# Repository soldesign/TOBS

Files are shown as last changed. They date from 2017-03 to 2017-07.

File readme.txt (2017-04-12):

Currently, 1.3 billion people live without access to electricity. Most of them are inhabitants of rural regions in developing south, that don’t have connection to the electricity grid. 
Fortunately, clean energy technologies have been reaching these people more and more in the past years. Mostly, but not only, in Bangladesh, a renewable energy revolution is taking place: the emergence of small scale solar-home-systems that supply electricity for lighting, cellphones and household appliances - in Bangladesh alone, there are already over 5 million solar-home-systems installed! These system feature a small PV panel with a charging controller and a battery (The solar home systems are usually financed with a micro loan from a microfinance institution, because its owner sometimes earn as little as one dollar per day).

To cut costs in these systems, lead-acid batteries are usually installed. Unfortunately, lead-acid batteries have a limited number of charge-discharge-cycles, much less than, for example, modern LIFEPO batteries. Also, they age quickly if they are discharged below around 40% of their capacity. This leads to many of the batteries breaking within 2 years or less, rendering the solar home systems unusable.

Moreover, as developing countries don’t have proficient infrastructure to dispose or recycle the lead-acid batteries, each failing battery leads to waste of resources and significant environmental pollution.

>lead acid batties are vulnurable to cycling often

How to solve the problem?

-retrofitting hybrid charge controller!

Using LIFEPO based batteries would significantly increase the solar home system’s lifetime­, as LIFEPO batteries are less affected by cycling compared to lead-acid batteries. However, initial high investment costs for LIFEPO batteries are often not feasible for developing markets. To get the best of both, a hybrid charge controller which supports a small lithium-ion battery and a bigger lead-acid battery simultaneously, would be ideal.

> LIFEPO batteries are better but too expensive 

A normal charge controller is responsible for monitoring the battery’s voltage and for controlling the charge and discharge cycle. In comparison, a hybrid charge controller would be able to switch between the two battery types, considering environmental factors, such as load current, solar irradiance and state of charge of both batteries. This will result in the li-ion battery having a smaller capacity, therefore cutting its cost. An algorithm would then only use the lead acid battery if the load is too big for the lithium ion battery to handle. For smaller loads and thus more cycles, the lithium ion battery would be used.

> lead acid battery will be cycled less often

Thus, the new hybrid charge controller aims to prolong the lifespan of millions of already existing lead acid batteries inside solar home systems by reducing sulfuration.

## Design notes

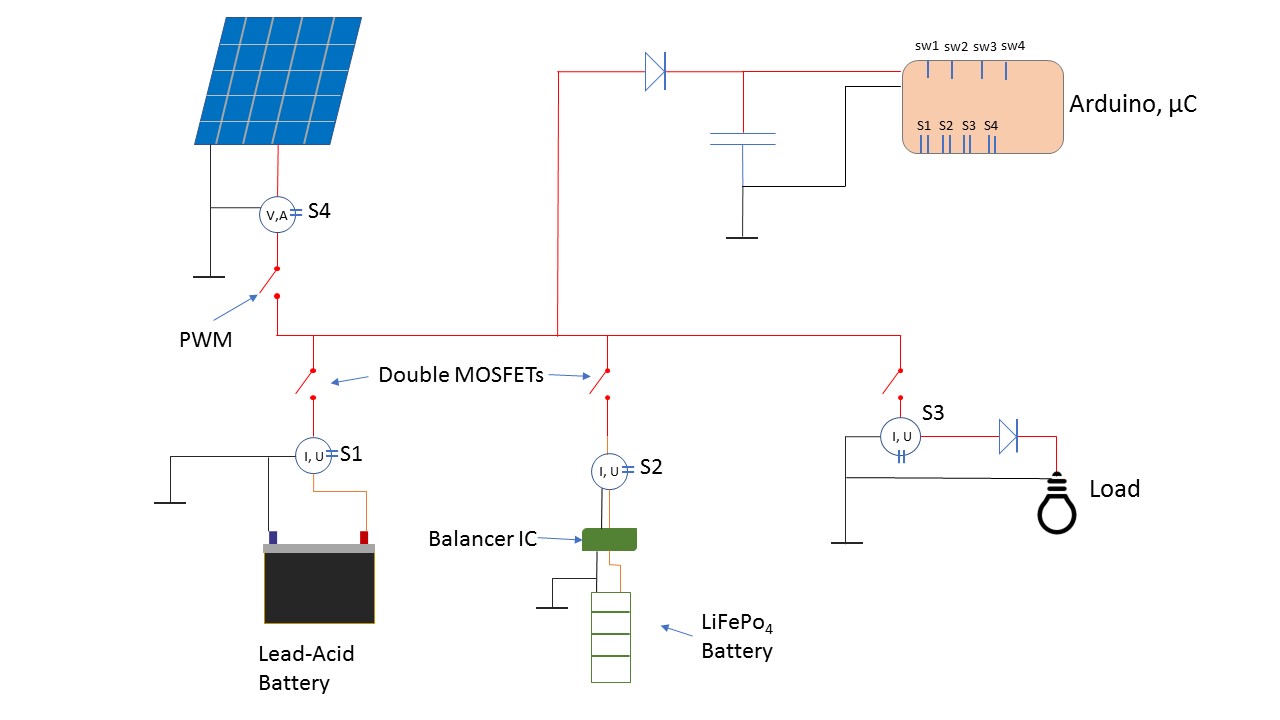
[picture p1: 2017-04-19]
TOBS-new pseudo schematic.jpg

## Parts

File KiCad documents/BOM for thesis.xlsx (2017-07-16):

Quantity | Value | Type | Price (10) | Price (100) | Reihenfolge | summ10 | summe100
1 | BQ76920 | Balancer | 2.87 | 2.77 | 1 | 2.87 | 2.77
1 | CD4051 | Multiplexer | 0.3 | 0.183 | 2 | 0.3 | 0.183
6 | IPD90P04P4L-04 | Power MOSFET | 1.15 | 0.875 | 3 | 6.9 | 5.25
2 | STL60P4LLF6 | MOSFET | 0.692 | 0.532 | 4 | 1.384 | 1.064
2 | BSS138 | Logic MOSFET | 0.159 | 0.066 | 5 | 0.318 | 0.132
6 | MMBT3904 | Logic transistor | 0.16 | 0.14 | 6 | 0.96 | 0.84
1 | VSB2045Y-M3/54 | Schottky | 0.967 | 0.829 | 7 | 0.967 | 0.829
1 | 1N4148-T | Diode | 0.022 | 0.018 | 8 | 0.022 | 0.018
3 | LM358D | Op-Amp | 0.266 | 0.144 | 9 | 0.798 | 0.432
2 | 15A | Fuse |  |  | 10 | 0 | 0
4 | R005 | Shunt |  |  | 11 | 0 | 0
6 | 220k | Resistor |  |  | 12 | 0 | 0
7 | 100k | Resistor |  |  | 13 | 0 | 0
5 | 47k | Resistor |  |  | 14 | 0 | 0
2 | 33k | Resistor |  |  | 15 | 0 | 0
17 | 10k | Resistor |  |  | 16 | 0 | 0
6 | 4.7k | Resistor |  |  | 17 | 0 | 0
1 | 2.2k | Resistor |  |  | 18 | 0 | 0
8 | 100 | Resistor |  |  | 19 | 0 | 0
2 | 10µ | Capacitor |  |  | 20 | 0 | 0
6 | 1µ | Capacitor |  |  | 21 | 0 | 0
3 | 0.1µ | Capacitor |  |  | 22 | 0 | 0
4 | 5mm pitch | Screw Terminal | 0.24 | 0.2 | 23 | 0.96 | 0.8
1 | 1x6 female | Pin header | 0.26 | 0.23 | 24 | 0.26 | 0.23
2 | 1x8 male | Pin header | 0.22 | 0.2 | 25 | 0.44 | 0.4
2 | 1x6 male | Pin header | 0.16 | 0.13 | 26 | 0.32 | 0.26
1 | 1x3 male | Pin header | 0.08 | 0.06 | 27 | 0.08 | 0.06
 |  | Sum | 16.579 | 13.268 |  | 16.579 | 13.268

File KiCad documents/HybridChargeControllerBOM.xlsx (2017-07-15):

Reference | Quantity | Value | Footprint | Readable Name | Type | SMD? | Price 10 | Price 100
AU1 | 1 | Uno Layout | Arduinos:ARDUINO_SHIELD_bigger_holes_no_outline | 2x8, 2x6 male | Pin header | n
C1 C2 C3 C4 C6 C7 | 6 | 1µ | Capacitors_SMD:C_0603_HandSoldering | 1µ | Capacitor | y
C11 C9 | 2 | 10µ | Capacitors_ThroughHole:CP_Radial_D5.0mm_P2.00mm | 10µ | Capacitor | n
C10 C5 C8 | 3 | 0.1µ | Capacitors_SMD:C_0603_HandSoldering | 0.1µ | Capacitor | y
D2 | 1 | 1N4148-T | Diodes_ThroughHole:D_DO-35_SOD27_P10.16mm_Horizontal | 1N4148-T | Diode | y
D3 | 1 | VSB2045Y-M3/54 | Diodes_ThroughHole:D_P600_R-6_P12.70mm_Horizontal | VSB2045Y-M3/54 | Diode | n
F1 F2 | 2 | 15A | Fuse_Holders_and_Fuses:Fuse_SMD1206_HandSoldering | 15A | Fuse | y
P1 P3 P5 P6 | 4 | Load | VCS_library:TerminalBlock_Screw_2pol | Terminal | Screw Terminal | n
P2 | 1 | LI_balancer | Pin_Headers:Pin_Header_Straight_1x03_Pitch2.54mm | 3 pin header male | Pin header | n
P4 | 1 | Extra | Pin_Headers:Pin_Header_Straight_1x05_Pitch2.54mm | 5 pin header female | Pin header | n
P7 | 1 | FTDI | Pin_Headers:Pin_Header_Straight_1x06_Pitch2.54mm | 6 pin header female | Pin header | n
Q1 Q10 Q3 Q6 Q7 Q8 | 6 | MMBT3904 | TO_SOT_Packages_SMD:SOT-23 | MMBT3904 |  | y
Q12 Q13 | 2 | STL60P4LLF6 | bachelorSMDs:powerFLAT_5x6_5..8com | STL60P4LLF6 |  | y
Q15 Q16 | 2 | BSS138 | TO_SOT_Packages_SMD:SOT-23 | BSS138 |  | y
Q11 Q14 Q2 Q4 Q5 Q9 | 6 | IPD90P04P4L-04 | TO_SOT_Packages_SMD:TO-252-3_TabPin2 | IPD90P04P4L-04 |  | y
R15 R21 R29 R34 R43 R47 | 6 | 4.7k | Resistors_SMD:R_0603_HandSoldering | 4.7k |  | y
R16 R17 R32 R44 | 4 | R005 | Resistors_SMD:R_1206_HandSoldering | shunt |  | y
R10 R14 R18 R2 R3 R4 R5 R6 | 8 | 100 | Resistors_SMD:R_0603_HandSoldering | 100 |  | y
R19 R20 R31 R36 R45 R46 | 6 | 220k | Resistors_SMD:R_0603_HandSoldering | 220k |  | y
R1 R11 R13 R22 R23 R24 R25 R26 R27 R33 R38 R48 R49 R53 R54 R55 R56 | 17 | 10k | Resistors_SMD:R_0603_HandSoldering | 10k |  | y
R28 R35 R39 R41 R51 R7 R9 | 7 | 100k | Resistors_SMD:R_0603_HandSoldering | 100k |  | y
R12 R30 R37 R50 R52 | 5 | 47k | Resistors_SMD:R_0603_HandSoldering | 47k |  | y
R40 | 1 | 2.2k | Resistors_SMD:R_0603_HandSoldering | 2.2k |  | y
R42 R8 | 2 | 33k | Resistors_SMD:R_0603_HandSoldering | 33k |  | y
U1 U4 U5 | 3 | LM358D | SMD_Packages:SOIC-8-N | LM358D |  | y
U2 | 1 | bq76920 | SMD_Packages:SSOP-20 | bq76920 |  | y
U3 | 1 | cd4051 | SMD_Packages:SO-16-N | cd4051 |  | y

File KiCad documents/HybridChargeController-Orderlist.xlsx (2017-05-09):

Reference | Quantity | Value | Auf Lager
C10 C5 C8 | 3 | 0.1µ | x
C1 C2 C3 C4 C6 C7 | 6 | 1µ | x
C11 C9 | 2 | 10µ | x
R1 R10 R14 R17 R2 R3 R4 R5 | 8 | 100 | x
R35 R39 R41 R7 R9 | 5 | 100k | x
R11 R13 R22 R23 R26 R28 R29 R38 R48 R49 R6 | 11 | 10k | x
F1 F2 | 2 | 15A | x
R24 R25 R27 | 3 | 1M | n
D1 D2 | 2 | 1N4148-T | n
R40 | 1 | 2.2k | n
R19 R20 R32 R36 R45 R46 | 6 | 220k | x
Q1 Q10 Q7 Q8 | 4 | MMBT3904 | n
R42 R8 | 2 | 33k | x
R15 R21 R30 R34 R43 R47 | 6 | 4.7k | n
R12 R31 R37 | 3 | 47k | n
U2 | 1 | bq76920 | n
Q4 | 1 | BSS138 | n
U3 | 1 | cd4051 | n
P4 | 1 | Extra | x
Q11 Q2 Q6 Q9 | 4 | IPD90P04P4_05 | n
P6 | 1 | LA | x
P5 | 1 | LI | x
P2 | 1 | LI_balancer | x
U1 U4 | 2 | LM358 | x
P1 | 1 | Load | x
P3 | 1 | PV | x
R16 R18 R33 R44 | 4 | R005 | x
Q3 Q5 | 2 | RQ3E100BNTB | n
Q12 Q13 | 2 | STL60P4LLF6 | n
AU1 | 1 | Uno Layout | x
D3 | 1 | VSB2045Y-M3/54 | n

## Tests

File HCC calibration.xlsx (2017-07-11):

 | Battery |  | PV |  | LOAD
 | Voltage |  | Voltage |  | Voltage
 | Input | Output | Input | Output | Input | Output
INPUT | 13360 | 679 | 10560 | 516.92 | 1 | 1
 | 11800 | 600 | 12140 | 596.83 | 0 | 0
 | 10320 | 525.6 | 14750 | 728.75
 | 14470 | 735.98
 | Current |  | Current |  | Current
 | Input | Output | Input | Output | Input | Output
INPUT | 31 | 487.85 | 0 | 492.9 | 0 | 495.35
 | 289 | 504.6 | 31.9 | 495.18 | 290 | 477.9
 | -5 | 485.83 | 326.4 | 513.5 | 2960 | 316.6
 | 3010 | 679.4 |  |  | 1990 | 375.7
 |  |  |  |  | 1120 | 428.4
PARAMETERS | Battery Voltage |  | PV Voltage |  | LOAD Voltage
 | 19.7333 | -45.9976 | 19.7805 | 334.8203 | 1.0000 | 0.0000
 | 1.0000 |  | 1.0000 |  | 1.0000
 | Battery Current |  | PV Current |  | LOAD Current
 | 15.5647 | -7564.6633 | 15.9332 | -7855.5799 | -16.5688 | 8210.8356
 | 0.9999984 |  | 0.9998 |  | 1.0000
OUTPUT | batterysensor.setcalibration(19.7333, -45.9976, 15.5647, -7564.6633); pvsensor.setcalibration(19.7805, 334.8203, 15.9332, -7855.5799); ldsensor.setcalibration(1, 0, -16.5688, 8210.8356);

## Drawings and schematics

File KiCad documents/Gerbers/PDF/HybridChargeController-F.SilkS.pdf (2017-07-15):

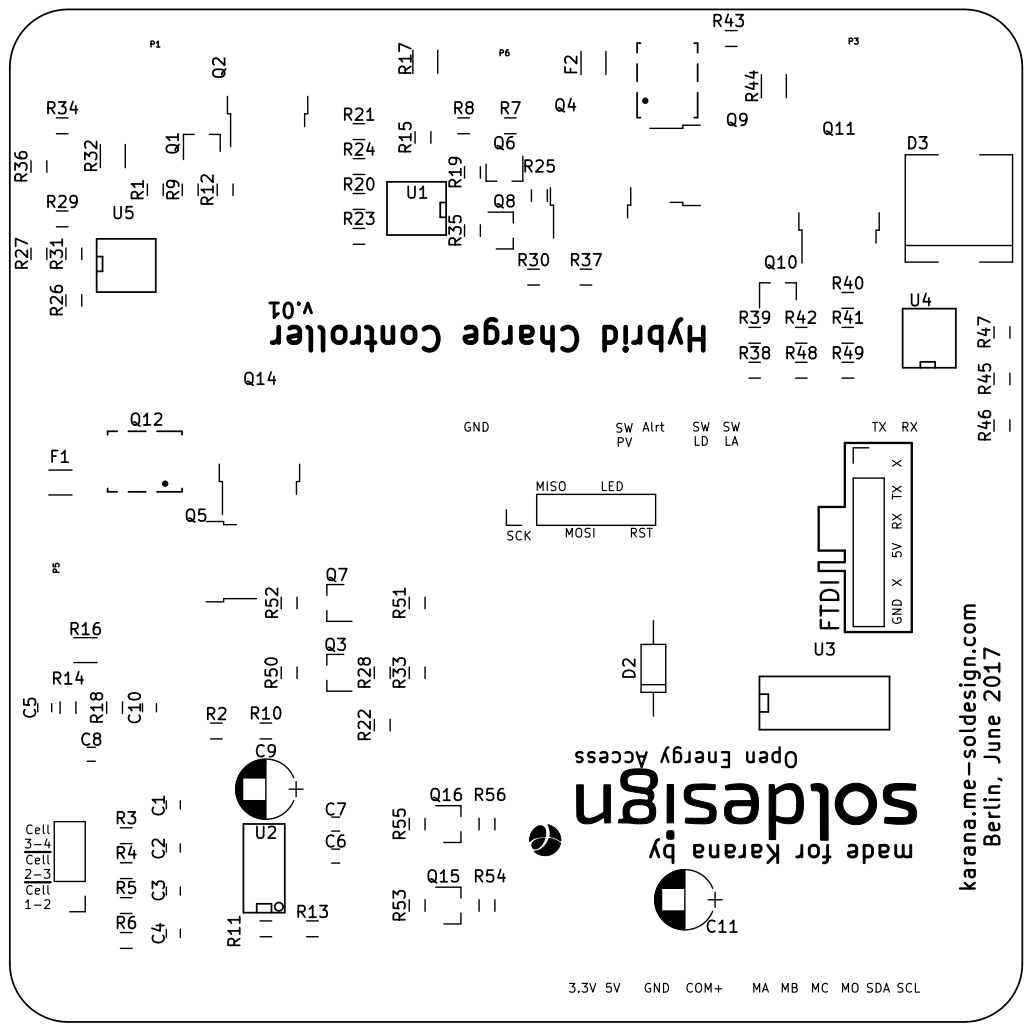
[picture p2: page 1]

FTDI X GND X 5V RX TX karana.me-soldesign.com Berlin, June 2017

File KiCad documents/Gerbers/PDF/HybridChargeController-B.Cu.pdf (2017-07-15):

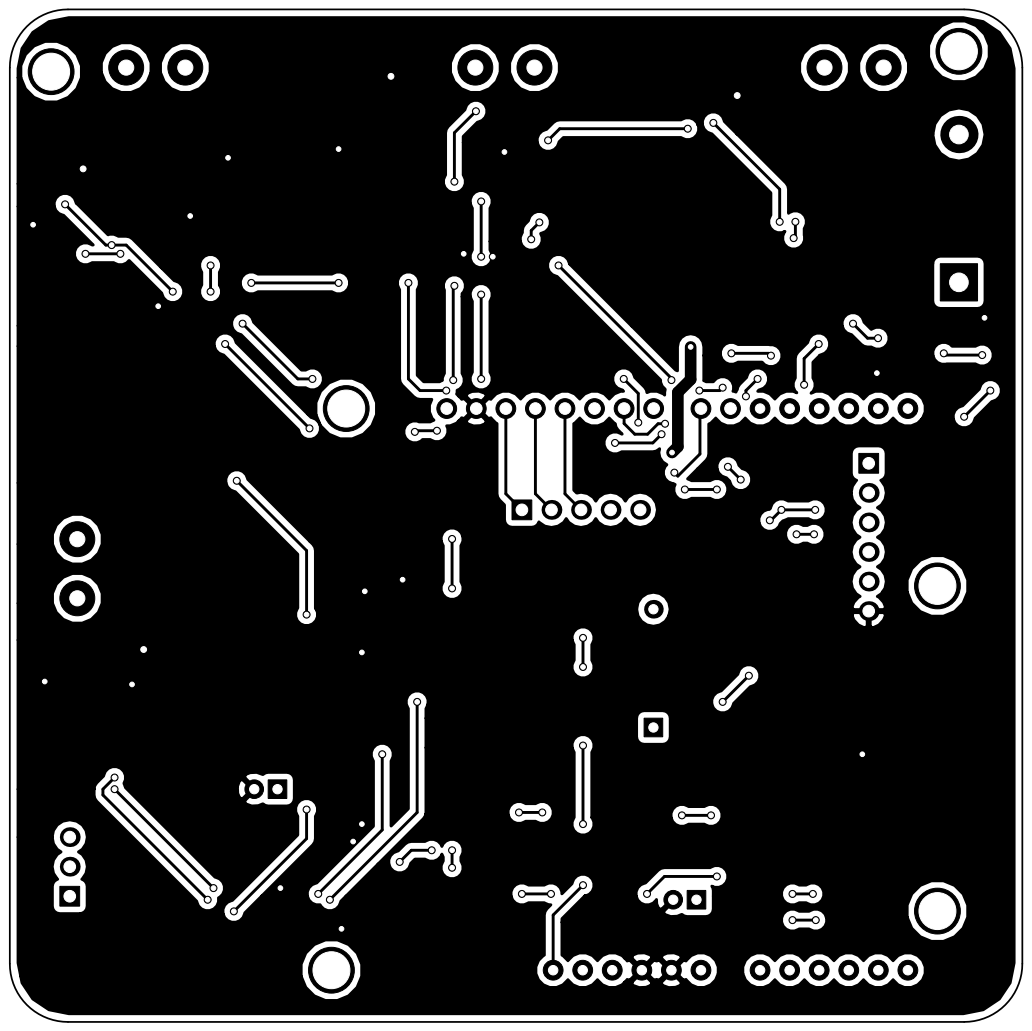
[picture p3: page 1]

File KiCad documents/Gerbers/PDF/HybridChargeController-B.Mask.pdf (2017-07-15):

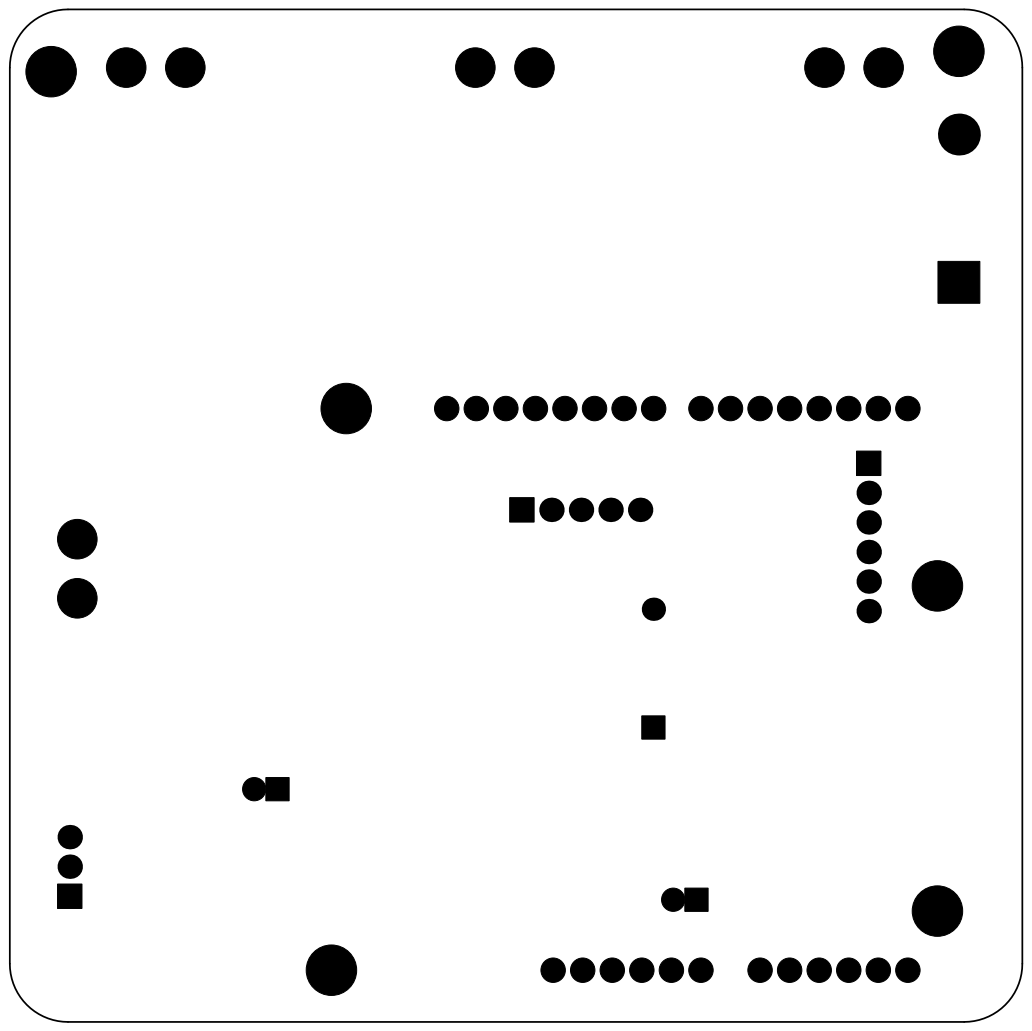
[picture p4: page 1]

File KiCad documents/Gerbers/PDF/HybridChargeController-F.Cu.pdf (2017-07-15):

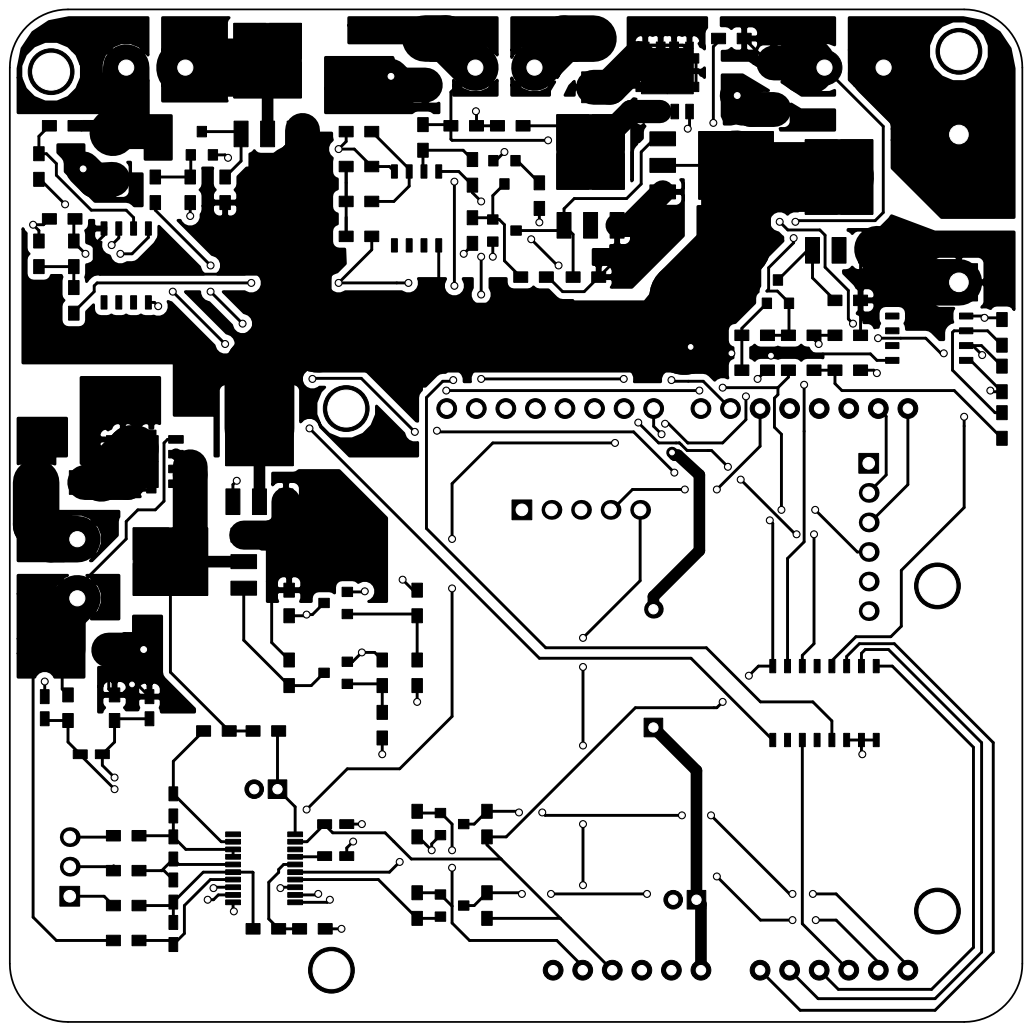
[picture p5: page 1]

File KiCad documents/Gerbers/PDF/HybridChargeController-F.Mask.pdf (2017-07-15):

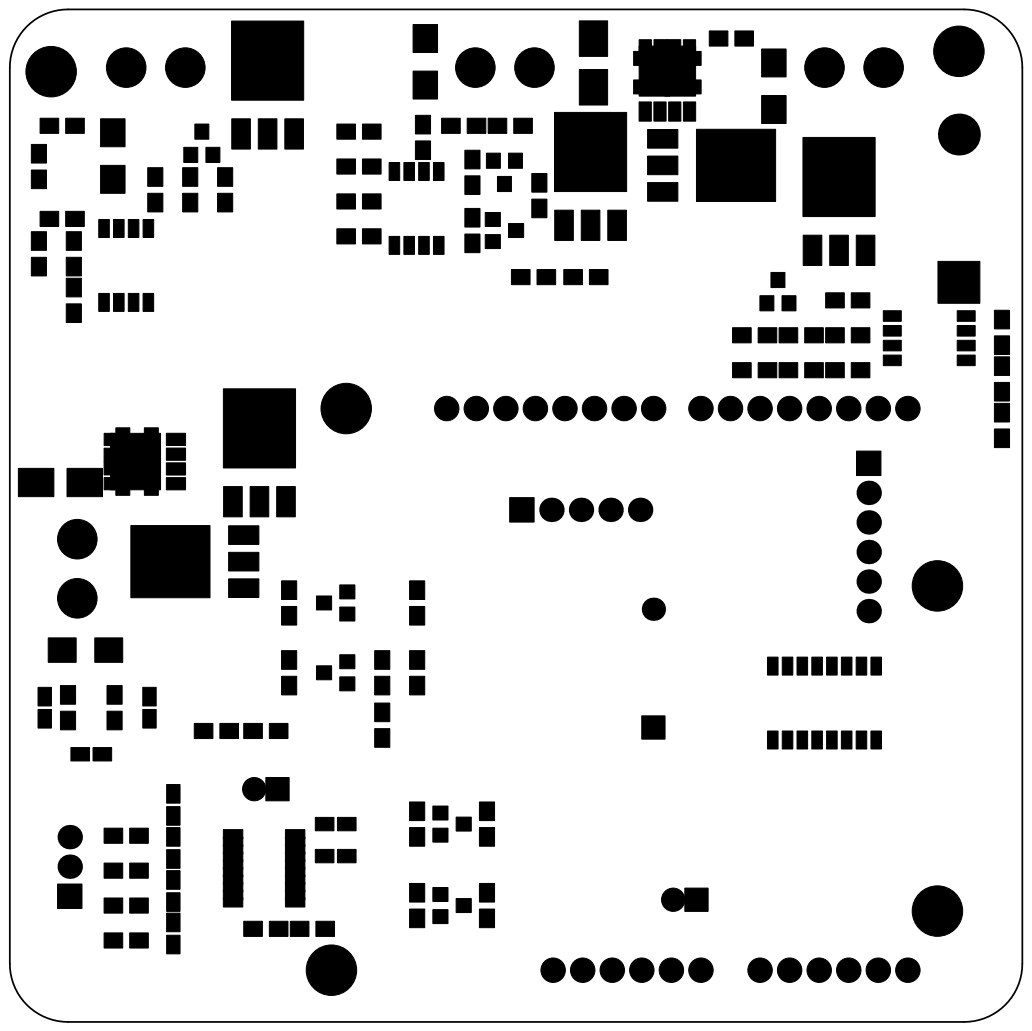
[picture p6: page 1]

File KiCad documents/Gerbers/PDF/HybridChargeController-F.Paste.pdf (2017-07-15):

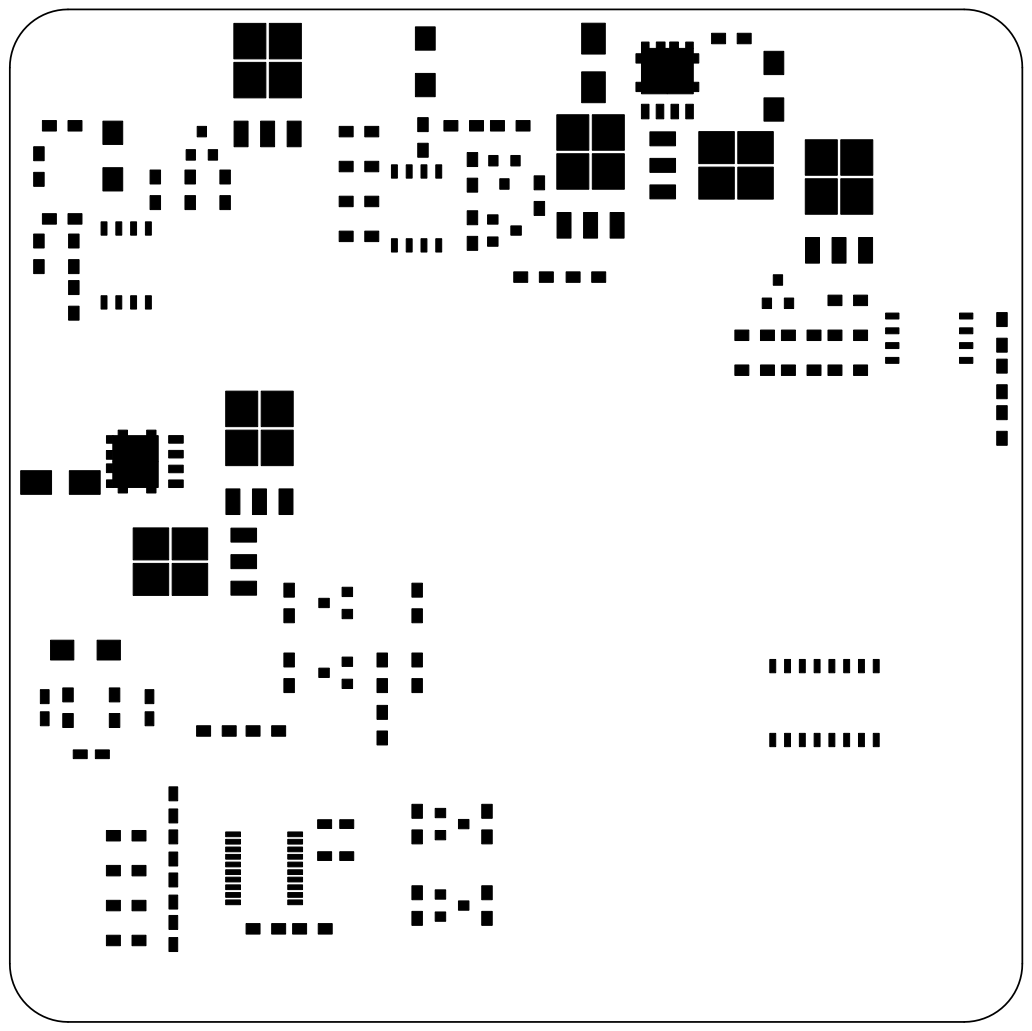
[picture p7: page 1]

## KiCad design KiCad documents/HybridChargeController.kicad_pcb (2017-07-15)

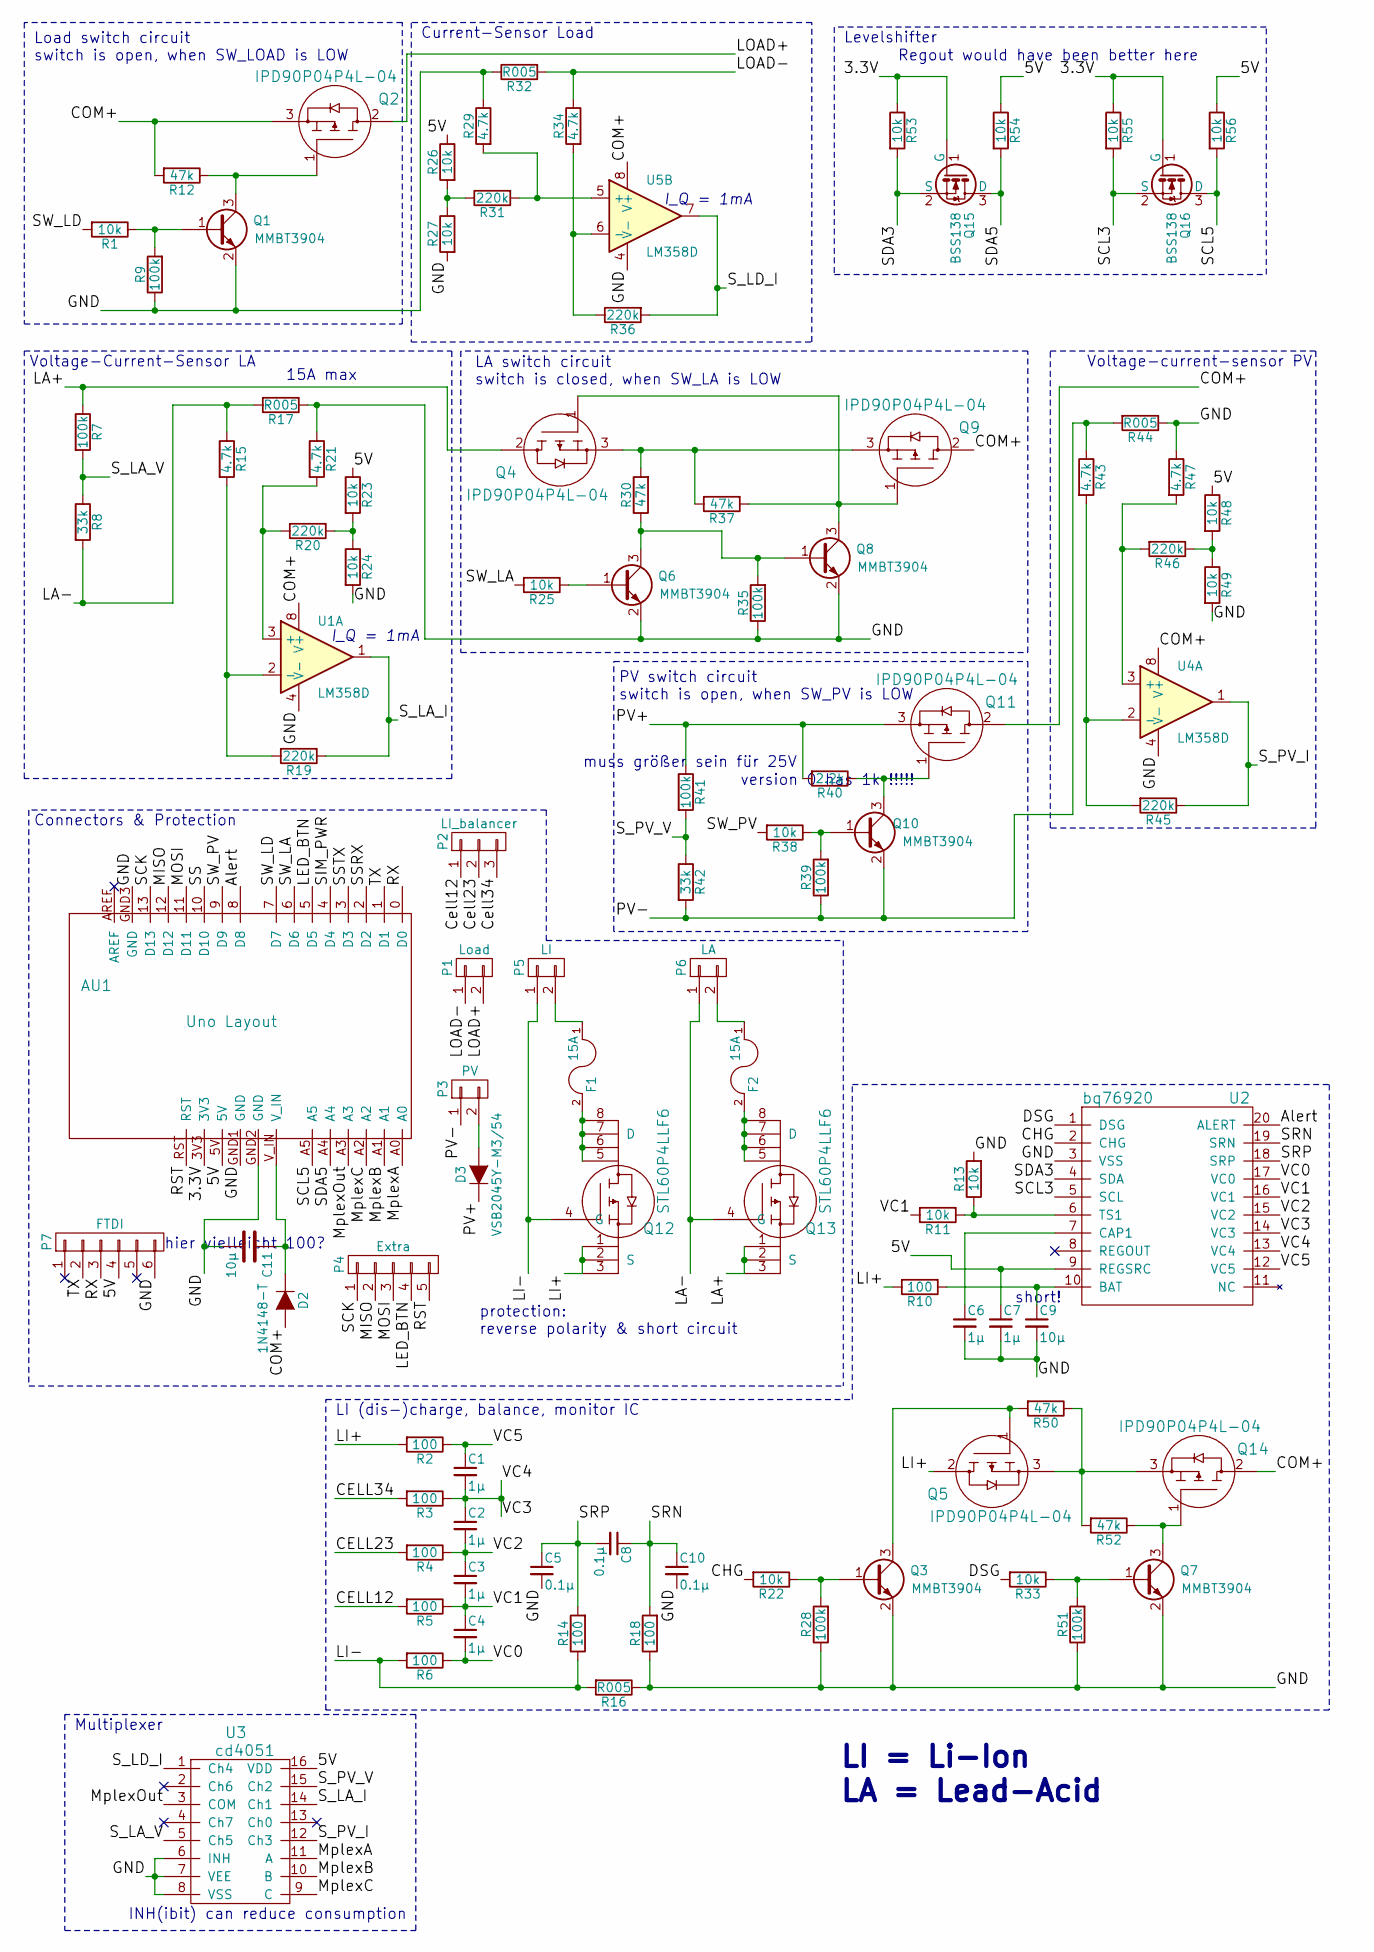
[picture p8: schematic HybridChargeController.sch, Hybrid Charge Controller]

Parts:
AU1: Uno Layout; ARDUINO_SHIELD_bigger_holes_no_outline
C1, C2, C3, C4, C6, C7: 1µ; C_0603_HandSoldering
C5, C8, C10: 0.1µ; C_0603_HandSoldering
C9, C11: 10µ; CP_Radial_D5.0mm_P2.00mm
D2: 1N4148-T; D_DO-35_SOD27_P10.16mm_Horizontal
D3: VSB2045Y-M3/54; D_P600_R-6_P12.70mm_Horizontal
F1, F2: 15A; Fuse_SMD1206_HandSoldering
P1: Load; TerminalBlock_Screw_2pol
P2: LI_balancer; Pin_Header_Straight_1x03_Pitch2.54mm
P3: PV; TerminalBlock_Screw_2pol
P4: Extra; Pin_Header_Straight_1x05_Pitch2.54mm
P5: LI; TerminalBlock_Screw_2pol
P6: LA; TerminalBlock_Screw_2pol
P7: FTDI; Pin_Header_Straight_1x06_Pitch2.54mm
Q1, Q3, Q6, Q7, Q8, Q10: MMBT3904; SOT-23
Q2, Q4, Q5, Q9, Q11, Q14: IPD90P04P4L-04; TO-252-3_TabPin2
Q12, Q13: STL60P4LLF6; powerFLAT_5x6_5..8com
Q15, Q16: BSS138; SOT-23
R1, R11, R13, R22, R23, R24, R25, R26, R27, R33, R38, R48, R49, R53, R54, R55, R56: 10k; R_0603_HandSoldering
R2, R3, R4, R5, R6, R10, R14, R18: 100; R_0603_HandSoldering
R7, R9, R28, R35, R39, R41, R51: 100k; R_0603_HandSoldering
R8, R42: 33k; R_0603_HandSoldering
R12, R30, R37, R50, R52: 47k; R_0603_HandSoldering
R15, R21, R29, R34, R43, R47: 4.7k; R_0603_HandSoldering
R16, R17, R32, R44: R005; R_1206_HandSoldering
R19, R20, R31, R36, R45, R46: 220k; R_0603_HandSoldering
R40: 2.2k; R_0603_HandSoldering
U1, U4, U5: LM358D; SOIC-8-N
U2: bq76920; SSOP-20
U3: cd4051; SO-16-N

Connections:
/3.3V: AU1.3V3, Q15.1 (G), Q16.1 (G), R53.1, R55.1
/5V: AU1.5V, C7.1, P7.4, R23.1, R26.1, R48.1, R54.1, R56.1, U2.9 (REGSRC), U3.16 (VDD)
/Alert: AU1.8 (D8), U2.20 (ALERT)
/CELL12: P2.1, R5.2
/CELL23: P2.2, R4.2
/CELL34: P2.3, R3.2
/CHG: R22.2, U2.2 (CHG)
/COM+: D2.2 (A), Q2.3, Q9.2, Q11.2, Q14.2, R12.2, U1.8 (V+), U4.8 (V+), U5.8 (V+)
/DSG: R33.2, U2.1 (DSG)
/GND: AU1.GND1 (GND), AU1.GND2 (GND), AU1.GND3 (GND), C5.2, C6.2, C7.2, C9.2, C10.2, C11.2, P7.6, Q1.2 (E), Q3.2 (E), Q6.2 (E), Q7.2 (E), Q8.2 (E), R9.1, R13.2, R16.1, R17.1, R18.1, R21.1, R24.2, R27.2, R28.1, R29.1, R32.1, R35.1, R44.1, R47.1, R49.2, R51.1, U1.4 (V-), U2.3 (VSS), U3.6 (INH), U3.7 (VEE), U3.8 (VSS), U4.4 (V-), U5.4 (V-)
/LA+: Q4.2, Q13.1, Q13.2 (S), Q13.3, R7.1
/LA-: P6.1, Q13.4 (G), R8.2, R15.1, R17.2
/LED_BTN: AU1.5 (D5), P4.4
/LI+: Q5.2, Q12.1, Q12.2 (S), Q12.3, R2.2, R10.2
/LI-: P5.1, Q12.4 (G), R6.2, R14.1, R16.2
/LOAD+: P1.2, Q2.2
/LOAD-: P1.1, R32.2, R34.1
/MISO: AU1.12 (D12), P4.2
/MOSI: AU1.11 (D11), P4.3
/MplexA: AU1.A0, U3.11 (A)
/MplexB: AU1.A1, U3.10 (B)
/MplexC: AU1.A2, U3.9 (C)
/MplexOut: AU1.A3, U3.3 (COM)
/PV+: D3.1 (K), Q11.3, R40.2, R41.1
/PV-: P3.1, Q10.2 (E), R39.1, R42.2, R43.1, R44.2
/RST: AU1.RST, P4.5
/RX: AU1.0 (D0), P7.3
/SCK: AU1.13 (D13), P4.1
/SCL3: Q16.2 (S), R55.2, U2.5 (SCL)
/SCL5: AU1.A5, Q16.3 (D), R56.2
/SDA3: Q15.2 (S), R53.2, U2.4 (SDA)
/SDA5: AU1.A4, Q15.3 (D), R54.2
/SIM_PWR: AU1.4 (D4)
/SRN: C8.1, C10.1, R18.2, U2.19 (SRN)
/SRP: C5.1, C8.2, R14.2, U2.18 (SRP)
/SS: AU1.10 (D10)
/SSRX: AU1.2 (D2)
/SSTX: AU1.3 (D3)
/SW_LA: AU1.6 (D6), R25.2
/SW_LD: AU1.7 (D7), R1.2
/SW_PV: AU1.9 (D9), R38.2
/S_LA_I: R19.1, U1.1, U3.14 (Ch1)
/S_LA_V: R7.2, R8.1, U3.5 (Ch5)
/S_LD_I: R36.2, U3.1 (Ch4), U5.7
/S_PV_I: R45.1, U3.12 (Ch3), U4.1
/S_PV_V: R41.2, R42.1, U3.15 (Ch2)
/TX: AU1.1 (D1), P7.2
/VC0: C4.2, R6.1, U2.17 (VC0)
/VC1: C3.2, C4.1, R5.1, R11.2, U2.16 (VC1)
/VC2: C2.2, C3.1, R4.1, U2.15 (VC2)
/VC3: C1.2, C2.1, R3.1, U2.13 (VC4), U2.14 (VC3)
/VC5: C1.1, R2.1, U2.12 (VC5)
unnamed: AU1.V_IN, C11.1, D2.1 (K)
unnamed: C6.1, U2.7 (CAP1)
unnamed: C9.1, R10.1, U2.10 (BAT)
unnamed: D3.2 (A), P3.2
unnamed: F1.1, P5.2
unnamed: F1.2, Q12.5, Q12.6, Q12.7 (D), Q12.8
unnamed: F2.1, P6.2
unnamed: F2.2, Q13.5, Q13.6, Q13.7 (D), Q13.8
unnamed: Q1.1 (B), R1.1, R9.2
unnamed: Q1.3 (C), Q2.1, R12.1
unnamed: Q3.1 (B), R22.1, R28.2
unnamed: Q3.3 (C), Q5.1, R50.2
unnamed: Q4.1, Q8.3 (C), Q9.1, R37.1
unnamed: Q4.3, Q9.3, R30.2, R37.2
unnamed: Q6.1 (B), R25.1
unnamed: Q6.3 (C), Q8.1 (B), R30.1, R35.2
unnamed: Q7.1 (B), R33.1, R51.2
unnamed: Q10.1 (B), R38.1, R39.2
unnamed: Q10.3 (C), Q11.1, R40.1
unnamed: Q7.3 (C), Q14.1, R52.1
unnamed: Q5.3, Q14.3, R50.1, R52.2
unnamed: R11.1, R13.1, U2.6 (TS1)
unnamed: R15.2, R19.2, U1.2 (-)
unnamed: R20.1, R23.2, R24.1
unnamed: R20.2, R21.2, U1.3 (+)
unnamed: R26.2, R27.1, R31.1
unnamed: R29.2, R31.2, U5.5 (+)
unnamed: R34.2, R36.1, U5.6 (-)
unnamed: R43.2, R45.2, U4.2 (-)
unnamed: R46.1, R48.2, R49.1
unnamed: R46.2, R47.2, U4.3 (+)

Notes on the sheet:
LA switch circuit switch is closed, when SW_LA is LOW
Load switch circuit switch is open, when SW_LOAD is LOW
Voltage-Current-Sensor LA
Current-Sensor Load
Voltage-current-sensor PV
Connectors & Protection
PV switch circuit switch is open, when SW_PV is LOW
LI = Li-Ion LA = Lead-Acid
I_Q = 1mA
LI (dis-)charge, balance, monitor IC
INH(ibit) can reduce consumption
Multiplexer
protection: reverse polarity & short circuit
15A max
short!
Levelshifter
Regout would have been better here
hier vielleicht 100?
muss größer sein für 25V
version 0 has 1k !!!!!

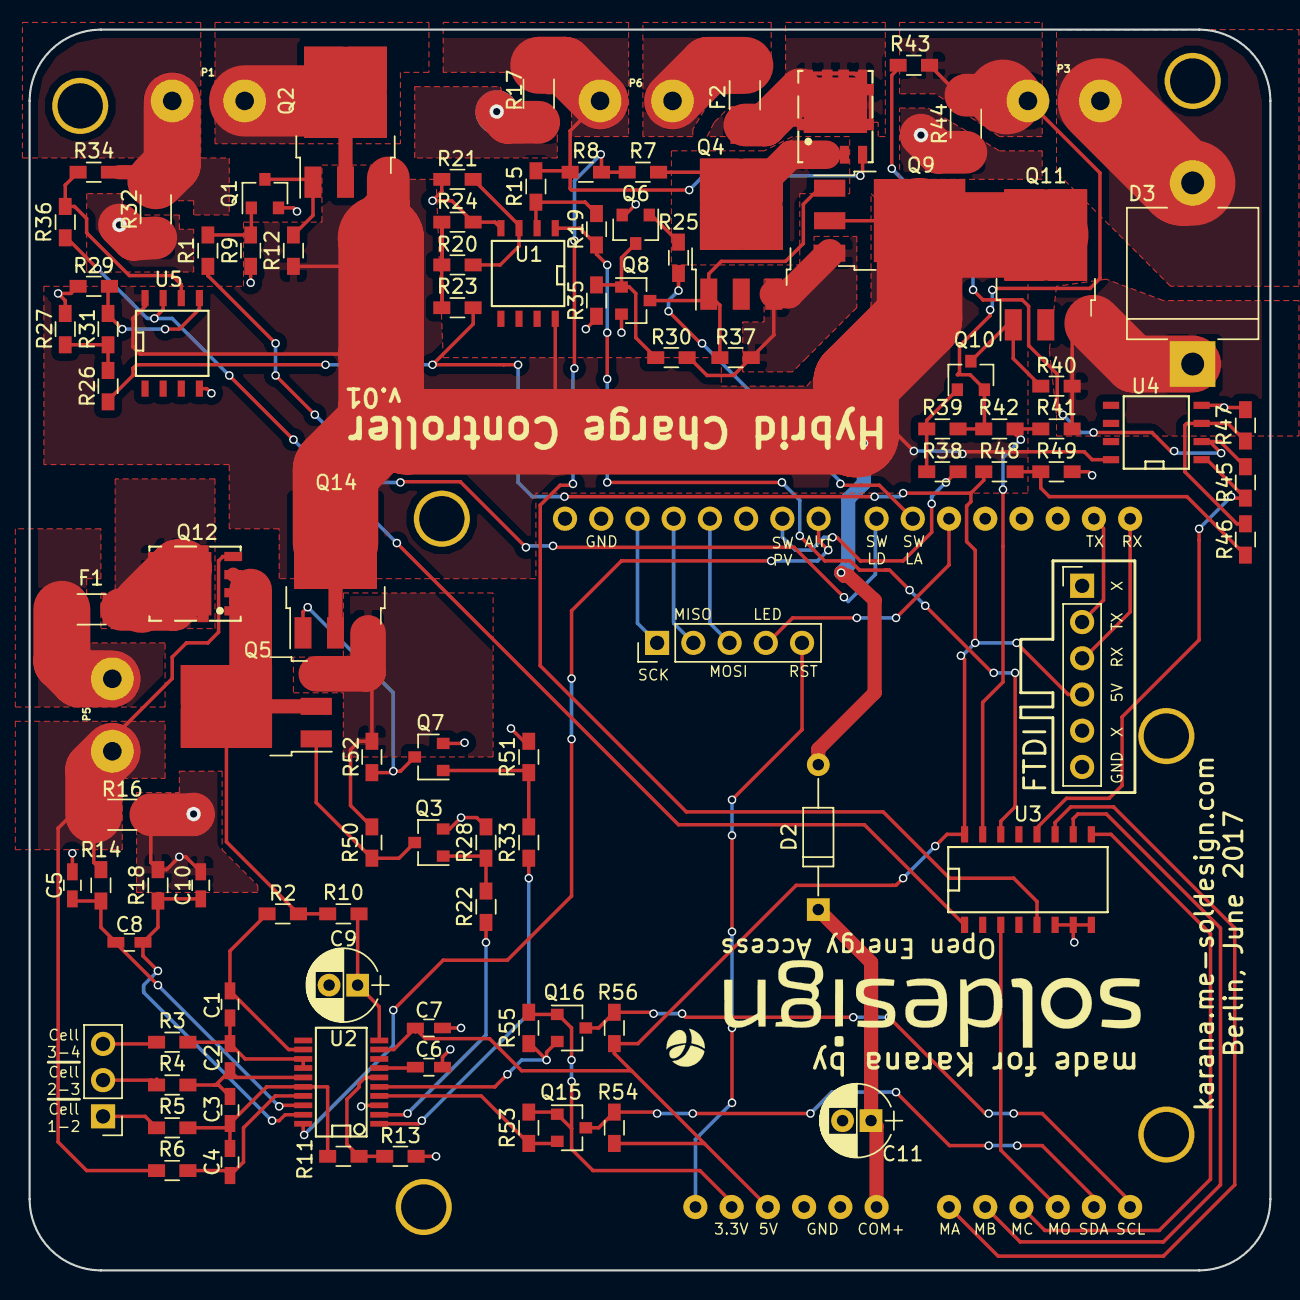
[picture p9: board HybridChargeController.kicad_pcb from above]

Board: 2 copper layers, 87.0 x 87.0 mm, 100 parts (0 on the bottom side), 79 nets.

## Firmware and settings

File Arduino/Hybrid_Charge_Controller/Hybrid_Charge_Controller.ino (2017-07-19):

//--------INCLUDES--------------
#include <bq769x0.h>    // Library for Texas Instruments bq76920 battery management IC
#include <PID_v1.h>			//PID library

//--------FOR TESTING--------------
unsigned long lastswitch = 0;

//--------DEBUG---------------------
const int PRINT_INTERVAL = 500;
unsigned long led_lighttime = 1000; //turn on led for 1 sec on startup

//--------BATTERY PARAMETERS------------
const double LA_CAPACITY = 2.3; //in Ah
const double LI_CAPACITY = 1.2;	//in Ah

//--------protection ratings------------
//LI handeled by balancer
const double LA_I_MAX_CHARGE = 5000;	//5A 
const double LA_I_MAX_DISCHARGE = 14000; //14A
const double LD_I_MAX = 14000; //14A
const double PV_I_MAX = 5000; //5A

const double LA_V_MAX = 16000;	//16V absolute maximum
const double PV_V_MAX = 25000; //25V if full irradiation and not charging

//--------calibration values--------------
const double LA_V_FACTOR  = 19.7333;
const double LA_V_SUMMAND = -45.9976;

const double LA_I_FACTOR  = 15.5647;
const double LA_I_SUMMAND = -7564.6633;

const double PV_V_FACTOR  = 19.7805;
const double PV_V_SUMMAND = 334.8203;
const double PV_I_FACTOR  = 15.9332;
const double PV_I_SUMMAND = -7855.5799;

const double LD_I_FACTOR  = -16.5688;
const double LD_I_SUMMAND = 8210.8356;

const double TEMPERATURE_FACTOR  = 0.2504;
const double TEMPERATURE_SUMMAND = -20.51;

const double OWN_CONSUMPTION = 20.0;

//--------charge protcoll values----------
//for testing
//const double V_ABS = 14650; //absorption voltage
const double V_ABS = 14650; 
const double V_EQU = 15500; //equalization voltage
const double V_FLT = 13250; //float voltage
const double LA_I_MIN_ABSORP = 20; // C-rate/100 !!!200 for testing usually 20!!!
const double PV_VOLTAGE_THRESHOLD = 100; //100mV PV v must be higher then actual battery voltage

//for testing some values
double la_soc = 98;
double li_soc = 99.99;

double la_i_history[10] = {0,0,0,0,0,0,0,0,0,0}; //stores older la_i's

const int SOC_CALC_INTERVAL = 1000; //to recalculate soc

//---------LA state definitions-------------
const byte LA_IDLE = 0;
const byte LA_DISCHARGE = 1;
const byte LA_BULK = 2;
const byte LA_ABSORP = 3;
const byte LA_EQUALIZE = 4;
const byte LA_FLOAT = 5;

//---------LI state definitions-------------
const byte LI_IDLE = 0;
const byte LI_DISCHARGE = 1;
const byte LI_CHARGE = 2;

//---------LD & PV state definitions-------------
const bool LD_OFF = 0;
const bool LD_ON = 1;

const bool PV_OFF = 0;
const bool PV_ON = 1;

//---------System state definitions-------------
const byte SYS_IDLE = 0;
const byte SYS_DISCHARGE = 1;
const byte SYS_CHARGE = 2;

const double SYS_IDLE_THRESHOLD = 30; //+-30mA don't count as charge or discharge THIS CAN NOT BE SMALLER THAN LA_I_MIN_ABSORP

//---------state variables-------------
byte la_state = 0;
byte li_state = 0;
bool pv_state = 1; 
bool ld_state = 1; 
byte sys_state = 0;

//-----------switching parameters---------
const double SWITCH_THRESHOLD = 400; //200mA discharge current

const bool LA_BATTERY = 0;
const bool LI_BATTERY = 1;

bool current_battery = 0; //LA
bool next_battery = 0; //LA

//-----------------Balancer initializations-------------------
#define BMS_ALERT_PIN 8       // balancer alert pin
#define BMS_BOOT_PIN -1       // there is no boot pin, balancer boots, whenever LiIon is connected
#define BMS_I2C_ADDRESS 0x18  // I2C adress of balancer

//-----------------pins-------------------
const byte LA_SW_PIN = 6; //LOW=closed
const byte PV_SW_PIN = 9; //HIGH=closed
const byte LD_SW_PIN = 7; //HIGH=closed
const byte MULTIPLEX_PIN_A = 14; //A0
const byte MULTIPLEX_PIN_B = 15; //A1
const byte MULTIPLEX_PIN_C = 16; //A2
const byte MULTIPLEX_PIN_OUT = 17; //A3
const byte LED_BTN_PIN = 5; //led and button pin
const byte TEMPERATURE_PIN = 21; //A7

//-----------PWM PI controller values-----------
double Input = 12600; 	//where the controller sets in for the first time
double duty_cycle = 255;	//controller output
double Setpoint = V_ABS-100;		//is set later on.

const double KD = 0;		//only PI needed.

const double V_KP = 0.2; 	//p-factor
const double V_KI = 0.3; 	//i-factor

const double I_KP = 0.2; 	//p-factor
const double I_KI = 0.3; 	//i-factor

//-----------------measurement------------------
const double SYS_MEASUREMENT_INACCURACY = 100; 	//100mA is acceptable for testing
const int NR_SAMPLES = 100;						//for measureing analog values
double la_v = 0;
double la_i = 0;
double li_v = 0;
double li_i = 0;
double la_i_average = 0;						//average of last 10 la_i's
double pv_v = 0;
double pv_i = 0;
double ld_i = 0;
double temperature = 0;
double measure_mistake = 0;
unsigned long last_li_measurement = 0;


//-----------------other------------------
bool multiplex_state_a = 0;
bool multiplex_state_b = 0;
bool multiplex_state_c = 0;
unsigned long lastprint = 0;
unsigned long last_soc = 0;

//-----------------objects------------------
bq769x0 BMS(bq76920, BMS_I2C_ADDRESS);    							// balancer object BMS = battery management system
PID myPID(&Input, &duty_cycle, &Setpoint, V_KP,V_KI, KD, DIRECT);		//PI - controller

void setup() {
	//pinModes-----------------
	pinMode(MULTIPLEX_PIN_A, OUTPUT);
	pinMode(MULTIPLEX_PIN_B, OUTPUT);
	pinMode(MULTIPLEX_PIN_C, OUTPUT);
	pinMode(MULTIPLEX_PIN_OUT, INPUT);
	pinMode(LA_SW_PIN, OUTPUT);
	pinMode(PV_SW_PIN, OUTPUT);
	pinMode(LD_SW_PIN, OUTPUT);

	//initial pin writing----------
	digitalWrite(LA_SW_PIN, LOW); //LA on
	digitalWrite(PV_SW_PIN, LOW); //PV off
	digitalWrite(LD_SW_PIN, LOW); //LD off

	//miscelaneous--------------
	TCCR1B = (TCCR1B & 0b11111000) | 0x05; //PWM frequency set to 60Hz
	Serial.begin(115200);
	

	Serial.println(F("Startup..."));

	//balancer setup
	int err = BMS.begin(BMS_ALERT_PIN, BMS_BOOT_PIN);

  	BMS.setTemperatureLimits(-20, 45, 0, 45);
  	BMS.setShuntResistorValue(5);						//5mOhm
  	BMS.setShortCircuitProtection(14000, 200);  		// delay in us
  	BMS.setOvercurrentChargeProtection(8000, 200);  	// delay in ms
  	BMS.setOvercurrentDischargeProtection(8000, 320);	// delay in ms
  	BMS.setCellUndervoltageProtection(2600, 2); 		// delay in s
  	BMS.setCellOvervoltageProtection(3650, 2);  		// delay in s
  	BMS.setBalancingThresholds(0, 3300, 20);  			// minIdleTime_min, minCellV_mV, maxVoltageDiff_mV
  	BMS.setIdleCurrentThreshold(100);					// 
  	BMS.enableAutoBalancing();							//let balancer handle balancing
	
  	//get both SOCs for the first time by getting voltages
	measure();
	guess_soc();
	Input = li_v;
	myPID.SetMode(AUTOMATIC);				//start PI-controller
}

void loop() {
	//soime excluded for testing
	measure();            	 	// read all sensor data
	protection();				//software protection for all devices
	BMS.update();  				// should be called at least every 250 ms
	calculate_SOCs();			// SOCs for both batteries
	set_sys_state();			// dis-/charging/idle
	select_battery();       	// LA or LI
	switchto_battery();			// LA or LI
	charge_protocol();      	// pwm charging of LA
	load_control();				// load on/off
 	pv_control();				// duty cycle here
	print_data();       	    // print to serial monitor
	led_handler();				// turn led on or off

	//pid tuning
	// Input = la_v;
	// if(Serial.available() > 0){
 //    	delay(10);
 //    	double P = Serial.parseFloat();
 //    	double I = Serial.parseFloat();
 //    	double D = Serial.parseFloat();
 //    	myPID.SetTunings(P, I, D);
	// }
}

void guess_soc(){
	la_soc = 0.087 * la_v - 1000; // taken from "Battery management for an off-grid PV system using flooded lead-acid batteries"
	
	last_soc = millis();
}

void measure(){
	la_v = get_value(1);
	la_i = -1 * get_value(2); // *-1 because defined like this
	pv_v = get_value(3);
	pv_i = get_value(4);
	ld_i = get_value(5);
	li_v = BMS.getBatteryVoltage();
	temperature = get_temperature();
	update_la_history();

	//there is a problem with spikes (up to +-6A) for li_i... this ignores spikes
	double last_li_i = li_i;
	if(li_i > last_li_i + 30 || li_i < last_li_i - 30){
		Serial.println(li_i);	//print if small spike
	}
	li_i = BMS.getBatteryCurrent();
	if(li_i > last_li_i + 1000){
		//Serial.print(F("SPIKE: "));
		//Serial.println(li_i);
		li_i = last_li_i;
	}
	if(li_i < last_li_i - 1000){
		//Serial.print(F("SPIKE: "));
		//Serial.println(li_i);
		li_i = last_li_i;
	}	
}

double get_value(byte measurepoint){
	set_multiplexchannel(measurepoint);
	delay(1);	//allow multiplexer to switch channels
	double temp_average_value = read_average_value();
	double temp_transformed_value = transform_average_value(temp_average_value, measurepoint);
	return temp_transformed_value;
}

void set_multiplexchannel(byte measurepoint){
	switch (measurepoint){
		case 1:	//la_v
			multiplex_state_a = 1;
			multiplex_state_b = 0;
			multiplex_state_c = 1;
			break;
		case 2:	//la_i
			multiplex_state_a = 1;
			multiplex_state_b = 0;
			multiplex_state_c = 0;
			break;
		case 3:	//pv_v
			multiplex_state_a = 0;
			multiplex_state_b = 1;
			multiplex_state_c = 0;
			break;
		case 4:	//pv_i
			multiplex_state_a = 1;
			multiplex_state_b = 1;
			multiplex_state_c = 0;
			break;
		case 5:	//ld_i
			multiplex_state_a = 0;
			multiplex_state_b = 0;
			multiplex_state_c = 1;
			break;
	}
	digitalWrite(MULTIPLEX_PIN_A, multiplex_state_a);
	digitalWrite(MULTIPLEX_PIN_B, multiplex_state_b);
	digitalWrite(MULTIPLEX_PIN_C, multiplex_state_c);
}

double read_average_value(){
	//take one value every timestep and summ it up, divide it
	double value = 0;
    for (int i = 0; i < NR_SAMPLES; i++) {
    	value = value + analogRead(MULTIPLEX_PIN_OUT);
    	delayMicroseconds(50);
  	}
  	value = value / NR_SAMPLES;
 	return value;
}

double transform_average_value(double temp_average_value, byte measurepoint){
	double value_factor = 0;
	double value_summand = 0;
	switch (measurepoint){
		case 1:	//la_v
			value_factor = LA_V_FACTOR;
			value_summand = LA_V_SUMMAND;
			break;
		case 2:	//la_i
			value_factor = LA_I_FACTOR;
			value_summand = LA_I_SUMMAND;
			break;
		case 3:	//pv_v
			value_factor = PV_V_FACTOR;
			value_summand = PV_V_SUMMAND;
			break;
		case 4:	//pv_i
			value_factor = PV_I_FACTOR;
			value_summand = PV_I_SUMMAND;
			break;
		case 5:	//ld_i
			value_factor = LD_I_FACTOR;
			value_summand = LD_I_SUMMAND;
			break;
	}
	double transformed_value = (temp_average_value * value_factor) + value_summand;
	return transformed_value;
}

double get_temperature(){
	//take one value every timestep and summ it up, divide it
	double temp_value = 0;
    for (int i = 0; i < NR_SAMPLES; i++) {
    	temp_value = temp_value + analogRead(TEMPERATURE_PIN);
    	delayMicroseconds(50);
  	}
  	temp_value = temp_value / NR_SAMPLES;
  	temp_value = TEMPERATURE_FACTOR * temp_value + TEMPERATURE_SUMMAND;
 	return temp_value;
}

void update_la_history(){
	//average of last 10 la_i, needed for comparing to minimum current threshold at charge protocol
	for(int i = 0; i<9; i++){
		la_i_history[i] = la_i_history[i+1];
	}
	
	la_i_history[9] = la_i;
	
	la_i_average = 0;
	for(int i = 0; i<10; i++){
		la_i_average = la_i_average + la_i_history[i];
	}
	la_i_average = la_i_average / 10;
}

void protection(){
	//LA battery protection
	//overvoltage
	if(la_v>LA_V_MAX){
		la_overvoltage();
	}
	//overdischarge
	if(la_i>LA_I_MAX_CHARGE){
		la_overcurrent();
	}
	//overcharge
	if(la_i<LA_I_MAX_DISCHARGE*(-1)){
		la_overcurrent();
	}

	//LD protection
	if(ld_i>LD_I_MAX){
		ld_overcurrent();
	}

	//PV protection
	if(pv_v>PV_V_MAX){
		pv_overvoltage();
	}
	if(pv_i>PV_I_MAX){
		pv_overcurrent();
	}

	//check if "current is lost somewhere"
	measure_mistake = -pv_i+la_i+li_i+ld_i + OWN_CONSUMPTION;
	if(abs(measure_mistake) > SYS_MEASUREMENT_INACCURACY){
		measure_error(measure_mistake);
	}
}

void la_overvoltage(){
	next_battery = LI_BATTERY;
	switchto_battery();
	ld_state = 0;
	load_control();
	pv_state = 0;
	pv_control();
	led_set(100000);
	Serial.println(F("LA OVERVOLTAGE... STOPPING"));
	Serial.println(la_v);
	while(true);
}

void la_overcurrent(){
	next_battery = LI_BATTERY;
	switchto_battery();
	ld_state = 0;
	load_control();
	pv_state = 0;
	pv_control();
	led_set(100000);
	Serial.println(F("LA OVERCURRENT... STOPPING"));
	Serial.println(la_i);
	while(true);
}

void ld_overcurrent(){
	ld_state = 0;
	load_control();
	pv_state = 0;
	pv_control();
	next_battery = LA_BATTERY; //can handle higher loads, thats why switching
	switchto_battery(); 
	led_set(100000);
	Serial.println(F("LOAD OVERCURRENT... STOPPING"));
	Serial.println(ld_i);
	while(true);
}

void pv_overvoltage(){
	pv_state = 0;
	pv_control();
	ld_state = 0;
	load_control();
	next_battery = LA_BATTERY; //can handle higher loads, thats why switching
	switchto_battery();
	led_set(100000);
	Serial.println(F("PV OVERVOLTAGE... STOPPING"));
	Serial.println(pv_v);
	while(true);
}

void pv_overcurrent(){
	pv_state = 0;
	pv_control();
	ld_state = 0;
	load_control();
	next_battery = LA_BATTERY; //can handle higher loads, thats why switching
	switchto_battery();
	led_set(100000);
	Serial.println(F("PV OVERCURRENT... STOPPING"));
	Serial.println(pv_i);
	while(true);
}

void measure_error(double mistake){
	//excluded fot testing
	/*
	pv_state = 0;
	pv_control();
	ld_state = 0;
	load_control();
	led_set(100000);
	Serial.print(F("MEASURE ERROR: "));
	Serial.println(mistake);
	*/
}

void calculate_SOCs(){ 		//simple coulomb counting
	//do it about every second (values need to be big enough)
	if(millis() > last_soc + SOC_CALC_INTERVAL){					
		//time since last soc calculation in ms
 		unsigned long timeinterval = (millis() - last_soc); 	
 		//same in seconds	
		double timeinterval_seconds = (double)timeinterval/1000; 	
		
		//used electric charge in mAh
		double used_mAh_la = la_i*timeinterval_seconds/3600;		
		la_soc = la_soc + (used_mAh_la/(LA_CAPACITY*10));			
		
		//only change LI_SOC if not in idle mode-> spikes were causing hughe differences
		if(li_state != LI_IDLE){
		//used electric charge in mAh
		double used_mAh_li = li_i*timeinterval_seconds/3600;		
		li_soc = li_soc + (used_mAh_li/(LI_CAPACITY*10));
		//for next round
		last_soc = millis();
		return;
		}
		last_soc = millis();								
	}
}

void set_sys_state(){
	//compare current pv and ld plus threshold
	if(pv_i >= ld_i + SYS_IDLE_THRESHOLD){ 
		sys_state = SYS_CHARGE;
	}else if(pv_i <= ld_i - SYS_IDLE_THRESHOLD){
		sys_state = SYS_DISCHARGE;
	}else{
		//only go in IDLE if duty_cycle is not small, otherwise still charging
		if(duty_cycle > 100){
			sys_state = SYS_IDLE;
		}else
		sys_state = SYS_CHARGE;
	}
}

void select_battery(){
	//load cuttof needs to be implemented here
	switch(sys_state){
		case SYS_IDLE:
			next_battery = LI_BATTERY;
		break;
		case SYS_CHARGE:
			if(li_soc < 100){ //only if LI is full LA gets charged
				next_battery = LI_BATTERY;
			}else{
				next_battery = LA_BATTERY;
			}
		break;
		case SYS_DISCHARGE:
			if(la_soc > 60){//if la has enough
				if(ld_i - pv_i >= SWITCH_THRESHOLD){ //if more then 0.5A dischare current
					next_battery = LA_BATTERY;
				}else{	//less then 0.5A discharge
					if(li_soc>60){ //if LI has enough
						next_battery = LI_BATTERY;
					}else{ //if not
						next_battery = LA_BATTERY;
					}
				}
			}else{//if la has not enough
				next_battery = LI_BATTERY;
			}
		break;
	}
	/*
	//switch every 2 sec for testing
	if(millis()> lastswitch + 2000){ 
		lastswitch = millis();
		if(current_battery == LA_BATTERY){
			next_battery = LI_BATTERY;
		}else{
			next_battery = LA_BATTERY;
		}
	}
	*/
}

void switchto_battery(){
	if(current_battery != next_battery){ //only if switch is needed
		switch(next_battery){
			case LA_BATTERY:
				digitalWrite(LD_SW_PIN, LOW); 		//turn LOAD off
				digitalWrite(LED_BTN_PIN, LOW); 	//turn LED off
				delay(100);
				BMS.disableDischarging();			//turn LI on
				delay(10);
				digitalWrite(LA_SW_PIN, LOW); 		//turn LA on
				delay(100);
				if(ld_state == LD_ON){
				digitalWrite(LD_SW_PIN, HIGH); 		//turn LOAD on if its supposed to be on
				}
			break;
			
			case LI_BATTERY: 
				digitalWrite(LD_SW_PIN, LOW); //turn LOAD off
				digitalWrite(LED_BTN_PIN, LOW); //turn LED off
				delay(100);
				digitalWrite(LA_SW_PIN, HIGH); //turn LA off
				delay(10);
				BMS.enableDischarging();		//turn LI on
				delay(100);
				if(ld_state == LD_ON){
					digitalWrite(LD_SW_PIN, HIGH); 	//turn LOAD on if its supposed to be on
				}
			break;
		}
		current_battery = next_battery;
	}
}

void charge_protocol(){
	//only execute if not discharging

	if(sys_state == SYS_CHARGE){
		if(current_battery == LA_BATTERY){
			execute_la_chargemode();
			li_state = LI_IDLE;
		}else{
			execute_li_chargemode();
			la_state = LA_IDLE;
		}
	}else if(sys_state == SYS_IDLE){
			la_state = LA_IDLE;
			li_state = LI_IDLE;
	}else if(sys_state == SYS_DISCHARGE){
		if(current_battery == LA_BATTERY){
			la_state = LA_DISCHARGE;
		}else{
			li_state = LI_DISCHARGE;
		}
	}
}

void execute_la_chargemode(){
	//explanation of this is in the thesis (flowchart)
	if(la_state == LA_FLOAT){
		la_state = LA_FLOAT;
		floatmode();
	}else{	
		if(la_v <= (V_ABS-100) & la_state != LA_ABSORP){
			la_state = LA_BULK;
			bulkmode();
		}else{
			if(la_state == LA_EQUALIZE){
				if(la_i_average<=LA_I_MIN_ABSORP & duty_cycle < 200){ //added duty cycle otherwise unwanted execution
					la_soc = 100;
					la_state = LA_FLOAT;
					floatmode();
				}else{
					la_state = LA_EQUALIZE;
					equalizemode();
				}
			}else if(la_state == LA_ABSORP){
				if(la_i_average<=LA_I_MIN_ABSORP & duty_cycle < 200){//added duty cycle otherwise unwanted execution
					la_soc = 100;
					la_state = LA_FLOAT;
					floatmode();
				}else{
					la_state = LA_ABSORP;
					absorpmode();
				}
			}else{
				if(equalize_due()){
					la_state = LA_EQUALIZE;
					equalizemode();
				}else{
					la_state = LA_ABSORP;
					absorpmode();
				}
			}
		}
	}
}

void execute_li_chargemode(){
	li_state = LI_CHARGE;
	Input = li_v;
	Setpoint = 14000;	//for testing
}

bool equalize_due(){
	//timemanagement needed
	return 0; //not due
}

void bulkmode(){
	//excluded for testing (still needs tweaking)
	//la current up to LA_I_MAX_CHARGE with PI controller
	Setpoint = V_ABS;
}

void absorpmode(){
	//la voltage limited to hold at V_ABS with PI controller
	Input = la_v;
	Setpoint = V_ABS;
}

void floatmode(){
	//la voltage limited to hold at V_FLT with PI controller
	Input = la_v;
	Setpoint = V_FLT;
}

void equalizemode(){
	// la voltage limited to hold at V_EQU with PI controller
	Input = la_v;
	Setpoint = V_EQU;
}

void load_control(){
	if(ld_state==LD_ON){
		digitalWrite(LD_SW_PIN, HIGH);
	}else{
		digitalWrite(LD_SW_PIN, LOW);
	}
}

void pv_control(){
	
	myPID.Compute();			//execute PI calculation, will alter duty_cycle if necessary
	
	//only allow pv switch to open, if pv_state = PV_ON which means no error
	if(pv_state == PV_ON){
		analogWrite(PV_SW_PIN,duty_cycle);	//apply duty cyle
	}else{
		digitalWrite(PV_SW_PIN, LOW); //turn off pv pin
	}
}

double active_bat_v(){
	//gives voltage of active battery
	if(current_battery == LA_BATTERY){
		return la_v;
	}else{
		return li_v;
	}
}

double active_bat_i(){
	//gives current of active battery
	if(current_battery == LA_BATTERY){
		return la_i;
	}else{
		return li_i;
	}
}

void led_handler(){
	//if led_lighttime is not reached, turn in led
	if(millis() < led_lighttime){
		digitalWrite(LED_BTN_PIN, HIGH);
	}else{
		digitalWrite(LED_BTN_PIN, LOW);
	}
}

void led_set(unsigned long shinetime){
	//set new time to turn off led
	led_lighttime = millis() + shinetime;
	led_handler();
}
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

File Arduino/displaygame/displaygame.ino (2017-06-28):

#include <Wire.h>
#include <Adafruit_MCP23017.h>
#include <Adafruit_RGBLCDShield.h>
Adafruit_RGBLCDShield lcd = Adafruit_RGBLCDShield();
#define WHITE 0x7
int row = 0;
int col = 0;
int rowd = 0;
int cold = 0;
int srow = 0;
int scol = 0;
int scold = 1;
int erow = 0;
int ecol = 0;
int ecold = -1;
unsigned long lastshow = 0;
unsigned long lastenemy = 0;
bool shot = false;
bool enemy = false;

void setup() {
  Serial.begin(9600);
  lcd.begin(16, 2);
  lcd.setBacklight(WHITE);
}

uint8_t i=0;
void loop() {
  //if(millis() >= lastshow+100 & rowd!= 0 || cold!= 0 || shot){
   if(millis() >= lastenemy+4000 & enemy == false){
      enemy = true;
      ecol = 16;
      erow = 1;
    };
  if(millis() >= lastshow+400){
     lastshow = millis();
     lcd.clear();

   if(enemy){
   byte ene[8] = {
    B10001,
    B01010,
    B11100,
    B11100,
    B01010,
    B10001,
  };
  ecol = ecol+ecold;
  if(ecol<0){
    enemy = false;
    }
  if(scol>15){ecol = 15;}
  
  
    lcd.createChar(2,ene);
    lcd.setCursor(ecol,erow);
    lcd.write((byte)2);
   }
   
  
  byte ship[8] = {
    B10000,
    B11000,
    B11111,
    B11111,
    B11000,
    B10000,
  };

  row = row+rowd;
  if(row<0){row=0;}
  if(row>1){row=1;}
  col = col+cold;
  if(col<0){col=0;}
  if(col>15){col=15;}

  rowd=0;
  cold=0;
  
  scol = scol+scold;
  if(scol<0){scol=0;}
  if(scol>15){
    shot = false;
    }
  

  lcd.createChar(0,ship);
  lcd.setCursor(col, row);
  lcd.write((byte)0);

   if(shot){
   byte bul[8] = {
    B00000,
    B00000,
    B11111,
    B11111,
    B00000,
    B00000,
  };
  
  
    lcd.createChar(1,bul);
    lcd.setCursor(scol,srow);
    lcd.write((byte)1);
   }

  
  //Serial.println(row);
  //Serial.println(col);
  
  }
  
  uint8_t buttons = lcd.readButtons();
  if (buttons) {
    }
    if (buttons & BUTTON_DOWN) {
      rowd = 1;
    }
    if (buttons & BUTTON_LEFT) {
      cold = -1;
    }
    if (buttons & BUTTON_RIGHT) {
      cold = 1;
    }
    if (buttons & BUTTON_UP) {
      rowd = -1;
    }
    if (buttons & BUTTON_SELECT){
      shot = true;
      scol = col;
      srow = row;
    }
    delay(50);
}

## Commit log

2017-03-23 created Kicad project
    [HybridChargeController.kicad_pcb, HybridChargeController.sch]
2017-03-27 switching mechanism ready to test
2017-03-27 switched to transistors maybe need 10k
    [HybridChargeController.sch]
2017-04-05 two mosfets on both power lines. working nicely
    [HybridChargeController.sch]
2017-04-12 added arduinouno footprint
    [HybridChargeController.sch]
2017-04-12 added two sensor circuits
    [HybridChargeController.sch, _saved_HybridChargeController.sch]
2017-04-12 added vcs PV and connectors
    [HybridChargeController.sch, _saved_HybridChargeController.sch]
2017-04-19 no changes?
    [HybridChargeController.sch]
2017-04-19 added only some comments and open questions for discussion
    [HybridChargeController.sch]
2017-04-19 new pseudo schematic
2017-04-21 added LI IC, removed own LI circuit part
    [HybridChargeController.sch]
2017-04-26 added multiplexer
    [HybridChargeController.sch]
2017-04-27 added protections
    [HybridChargeController.sch]
2017-04-27 selfmade STL60P4LLF6
    [HybridChargeController.sch]
2017-04-27 added extra connections
    [_saved_HybridChargeController.sch]
2017-04-27 order ready
    [HybridChargeController-Orderlist.xlsx, HybridChargeController.csv, HybridChargeController.sch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]
2017-05-09 added more footprints
    [HybridChargeController.sch]
2017-05-09 more and more footprints
    [HybridChargeController-Orderlist.xlsx, HybridChargeController.sch]
2017-05-09 started pcb
    [HybridChargeController.csv, HybridChargeController.sch]
2017-05-10 noticed low side switching
    [HybridChargeController.kicad_pcb, HybridChargeController.sch]
2017-05-16 going to switch on high side
2017-05-16 new branch highside switch
    [HybridChargeController.sch]
2017-05-16 implemented new HS switch
    [HybridChargeController.sch]
2017-05-16 startet distributing components
    [HybridChargeController.kicad_pcb, HybridChargeController.sch]
2017-05-16 completed vaguely arranging footprints
    [HybridChargeController.kicad_pcb, HybridChargeController.sch]
2017-05-17 power paths done
    [HybridChargeController.kicad_pcb, HybridChargeController.sch]
2017-05-17 more traces done
    [HybridChargeController.kicad_pcb, HybridChargeController.sch]
2017-05-18 almost all tracks done
    [HybridChargeController.kicad_pcb]
2017-05-18 ready for review
    [HybridChargeController.kicad_pcb]
2017-05-21 added a few comments for final check, played with the Silkscreen a bit
    [HybridChargeController.kicad_pcb, HybridChargeController.sch]
2017-05-22 added FTDI connector
    [HybridChargeController.kicad_pcb, HybridChargeController.sch]
2017-05-22 gerbered like this
    [HybridChargeController-B.Cu.gbr, HybridChargeController-B.Paste.gbr, HybridChargeController-Edge.Cuts.gbr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]
2017-05-23 new gerber files
    [HybridChargeController-B.Cu.gbr, HybridChargeController-B.Mask.gbr, HybridChargeController-B.Paste.gbr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]
2017-05-23 added ino file and NOTICED MISTAKE IN KICAT PIN 8 X 9
    [Hybrid_Charge_Controller.ino, SwitchBlink.ino]
2017-05-23 switched 8 and 9 and hope for the best
    [HybridChargeController-B.Cu.gbr, HybridChargeController-B.Mask.gbr, HybridChargeController-Edge.Cuts.gbr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]
2017-05-24 fixed extra holes, send new gerbers
    [HybridChargeController-B.Cu.gbr, HybridChargeController-B.Mask.gbr, HybridChargeController-Edge.Cuts.gbr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]
2017-06-05 going to put schematic on A4
    [HybridChargeController.sch]
2017-06-06 sucessfully migrated to A4 for schematic
    [HybridChargeController.sch]
2017-06-15 played around with i2c
2017-06-19 added explanations schematic
    [HybridChargeController.kicad_pcb, HybridChargeController.sch, Schematics for explanations.kicad_pcb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]
2017-07-11 will alter PI controller into struct
    [HCC calibration.xlsx, HybridChargeController.csv, HybridChargeController.kicad_pcb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]
2017-07-11 pi solved, problem with balancer
    [Hybrid_Charge_Controller.ino]
2017-07-11 dont know what was wrong, everything is working now
    [Hybrid_Charge_Controller.ino]
2017-07-11 end of day
    [charge plot.xlsx]
2017-07-12 simple cc
    [charge plot.xlsx]
2017-07-13 first tests
    [charge plot.xlsx, charge plot_with source.xlsx, charge plot_with source_2.xlsx]
2017-07-14 going to check if actually charging at charge protocol
    [charge plot_with source.xlsx, switching_showcase.xlsx]
2017-07-14 trying PID library again
    [charge plot_with source_2.xlsx, charge plot_with source_PWM working.xlsx, switching_showcase.xlsx]
2017-07-15 going to strip down loop for pid calibration
    [HybridChargeController.kicad_pcb, HybridChargeControllerBOM.xlsx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]
2017-07-15 new controller works, trying to get rid of spikes
    [PWM_showcase.xlsx, chargeprotocol_showcase.xlsx]
2017-07-16 going to try less delay between measurements
    [BOM for thesis.xlsx, PWM_showcase.xlsx, chargeprotocol_showcase.xlsx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]
2017-07-19 last version of code before handing in thesis
    [HybridChargeController.sch, Schematics for explanations.sch, chargeprotocol_showcase3.xlsx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]
